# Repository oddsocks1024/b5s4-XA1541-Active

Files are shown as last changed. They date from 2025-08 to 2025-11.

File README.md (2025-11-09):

# b5s4-XA1541-Active
Read &amp; Write C64, C128 and VIC-20 disks directly on a PC using a Commodore drive

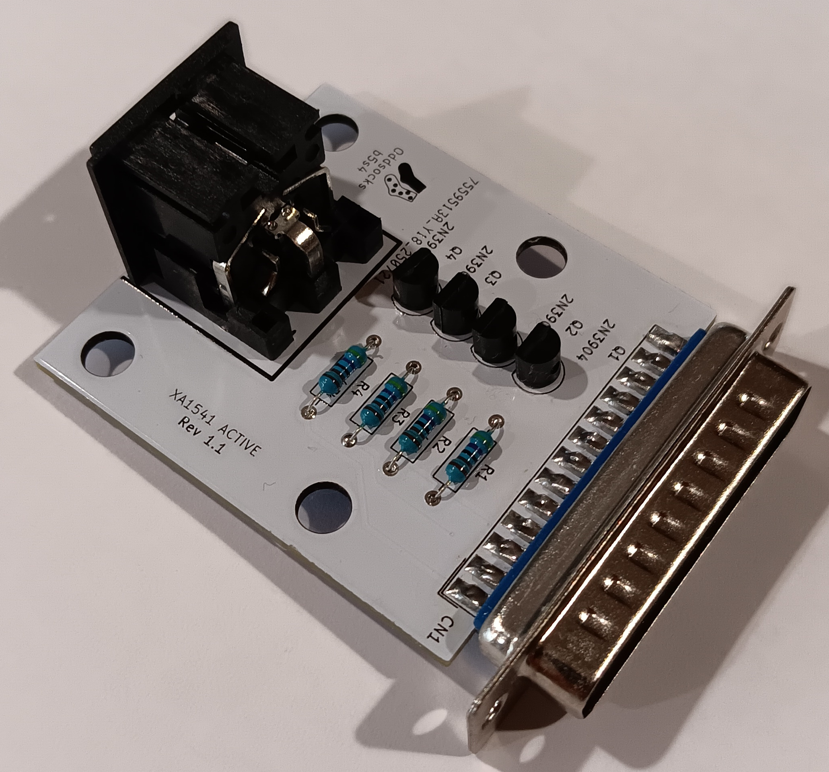
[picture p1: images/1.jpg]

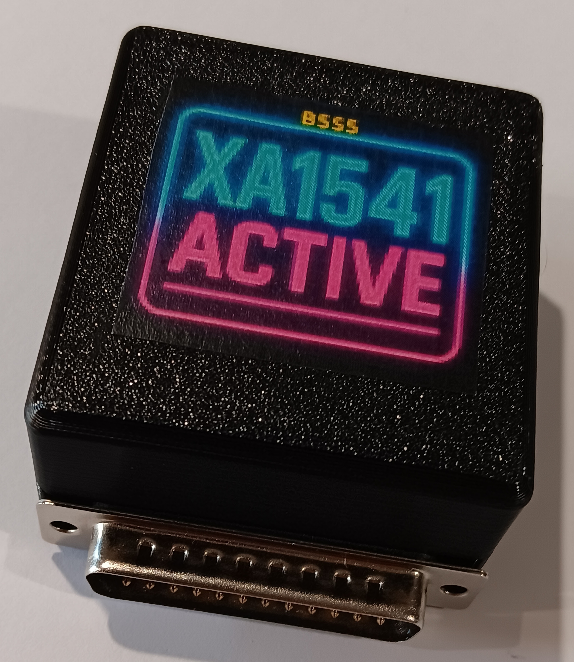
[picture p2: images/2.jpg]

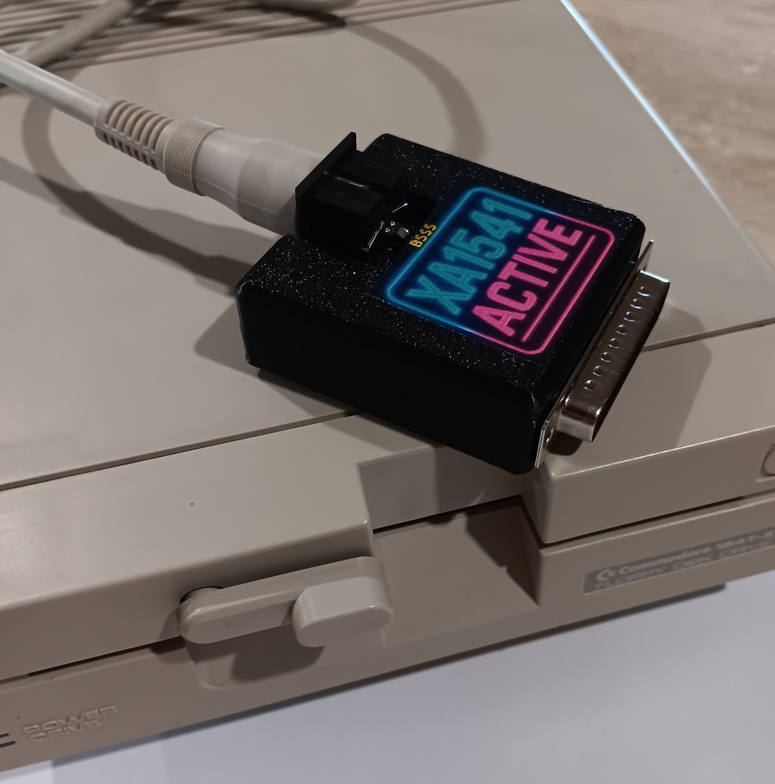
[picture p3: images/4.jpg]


## Description

This is the b5s4 PCB version of the XA1541 Active adapter. It lets you connect Commodore Floppy Disk drives to a PC with a Parallel
Port and read and write to those disks natively. See: https://sta.c64.org/xa1541.html for additional information.

**Compatible Floppy Drives**

* Commodore 1541
* Commodore 1541-II
* Commodore 1570
* Commodore 1571
* Commodore 1581
* ... and compatibles

**Compatible Software**

* The Star Commander
* OpenCBM
* NibTools
* CMBXfer
* Mtap & Ptap
* NIBTools
* cbm4linux

## Bill of Materials

| Qty | Component |
|:---:|---|
| 1 | Female DIN45322 connector |
| 1 | Male DB25 connector - straight - for edge mounting |
| 4 | 2N3904 transistors |
| 4 | 4.7KΩ Axial Resistors - 1/4 watt |

## 3D Printable Case
A 3D printable case specifically designed for this PCB is also available. STLs are included in this repo and there is also a [Thingiverse Page](https://www.thingiverse.com/thing:7099785)

* Designed to use screws as they produce a much nicer, more robust case
* 4 x 3.5mm self-tapping screws to attach the shells. Max length about 12mm

## Support Me
* [My Projects](https://projects.amiga-hardware.com) - Donate on this page
* [Order the PCB](https://www.pcbway.com/project/shareproject/b5s5_XA1541_Active_Read_Write_C64_C128_VIC20_disks_on_PC_ddd3c031.html)
* [Order the Case](https://www.pcbway.com/project/shareproject/b5s4_XA1541_Active_Case_Slimline_af867c8e.html)

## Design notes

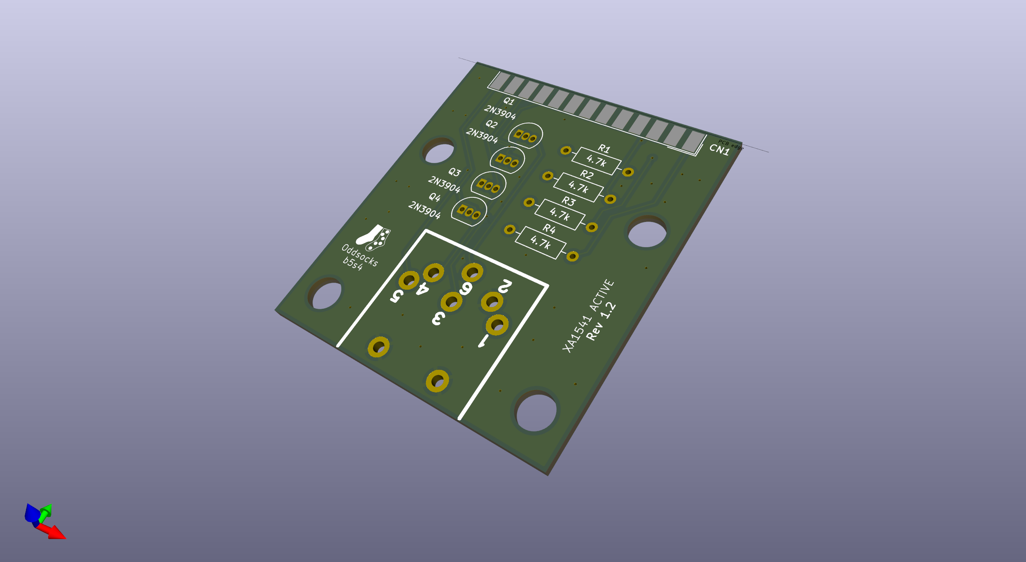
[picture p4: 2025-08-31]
images/b5s4-XA1541-active.png

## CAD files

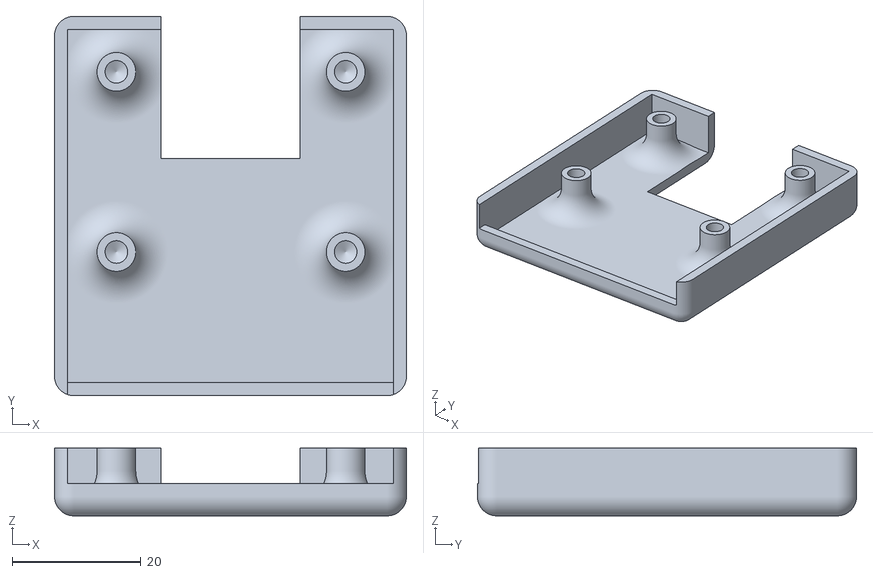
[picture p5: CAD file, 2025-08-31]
STL/XA1541-Active Slim - Top.stl
54.6 x 58.8 x 10.5

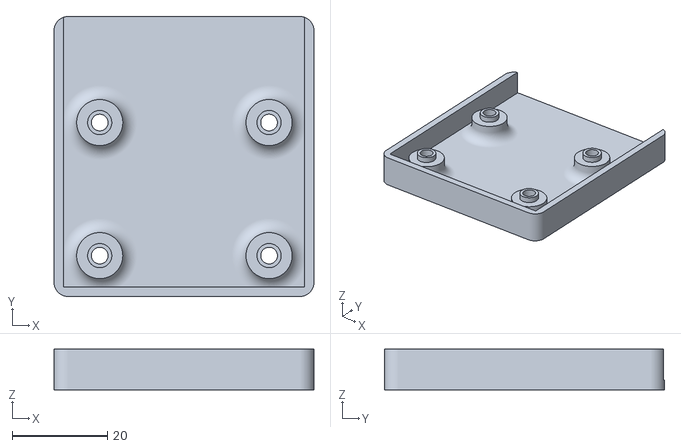
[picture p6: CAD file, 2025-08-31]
STL/XA1541-Active Slim - Bottom.stl
54.6 x 58.8 x 8.51

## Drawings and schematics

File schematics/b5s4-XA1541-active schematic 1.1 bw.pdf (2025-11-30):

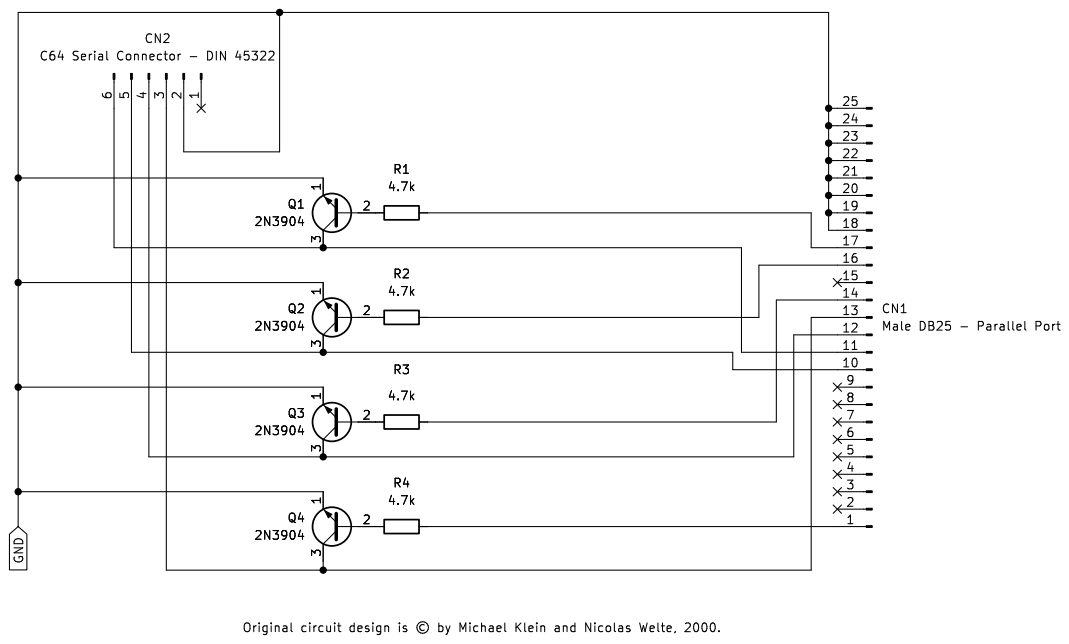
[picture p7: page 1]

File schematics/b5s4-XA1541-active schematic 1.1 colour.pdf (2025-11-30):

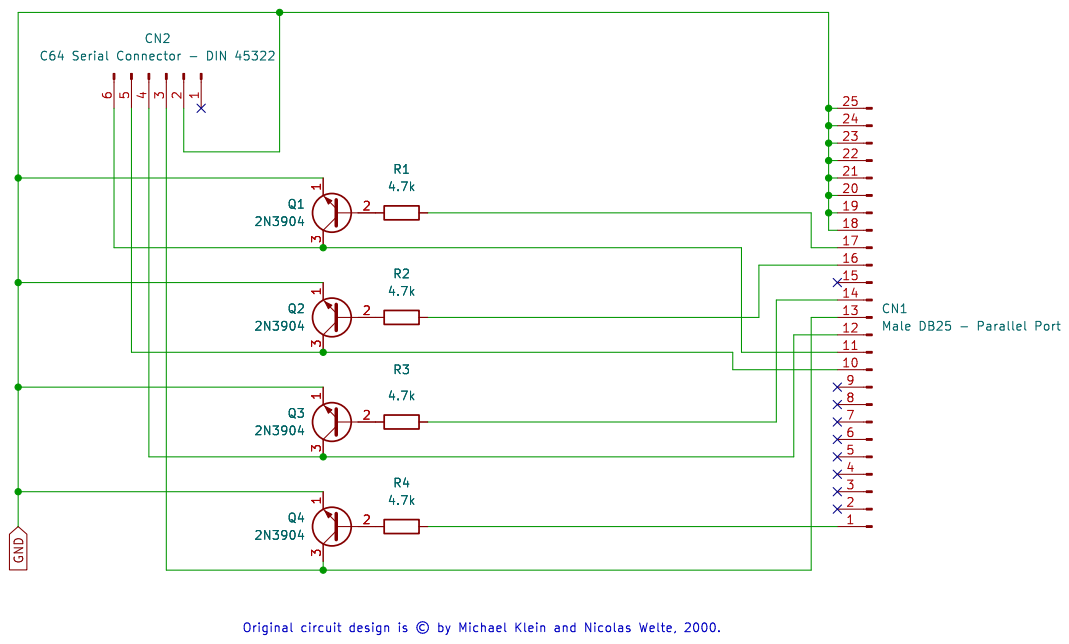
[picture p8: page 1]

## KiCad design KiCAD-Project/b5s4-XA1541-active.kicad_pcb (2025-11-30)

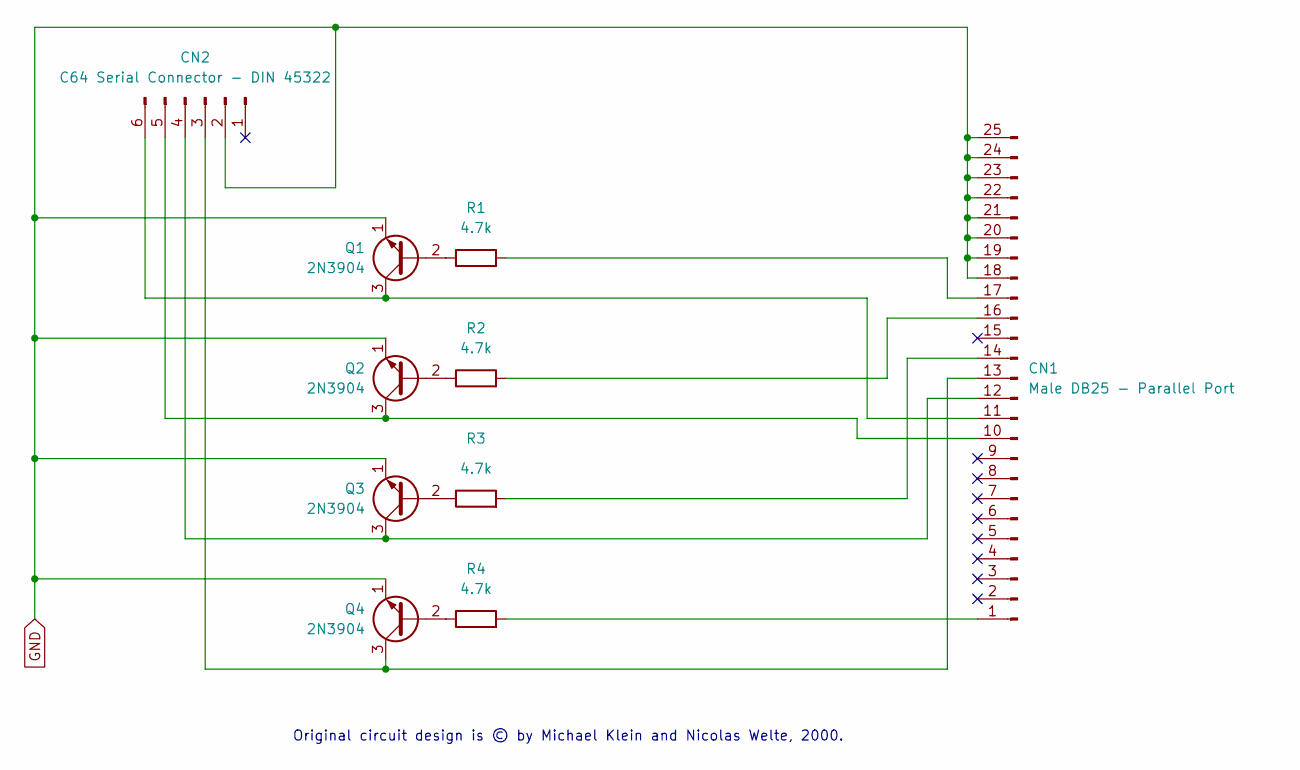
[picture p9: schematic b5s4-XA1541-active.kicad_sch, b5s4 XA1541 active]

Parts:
CN1: Male DB25 - Parallel Port; DSUB-25_Pins_EdgeMount_P2.77mm
CN2: C64 Serial Connector - DIN 45322; C64 Serial Connector
Q1, Q2, Q3, Q4: 2N3904; TO-92_Inline
R1, R2, R3, R4: 4.7k; R_Axial_DIN0207_L6.3mm_D2.5mm_P10.16mm_Horizontal

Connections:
GND: CN1.18, CN1.19, CN1.20, CN1.21, CN1.22, CN1.23, CN1.24, CN1.25, CN2.2, Q1.1 (E), Q2.1 (E), Q3.1 (E), Q4.1 (E)
unnamed: CN1.1, R4.2
unnamed: CN1.10, CN2.5, Q2.3 (C)
unnamed: CN1.11, CN2.6, Q1.3 (C)
unnamed: CN1.12, CN2.4, Q3.3 (C)
unnamed: CN1.13, CN2.3, Q4.3 (C)
unnamed: CN1.14, R3.2
unnamed: CN1.16, R2.2
unnamed: CN1.17, R1.2
unnamed: Q1.2 (B), R1.1
unnamed: Q2.2 (B), R2.1
unnamed: Q3.2 (B), R3.1
unnamed: Q4.2 (B), R4.1

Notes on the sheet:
Original circuit design is © by Michael Klein and Nicolas Welte, 2000.

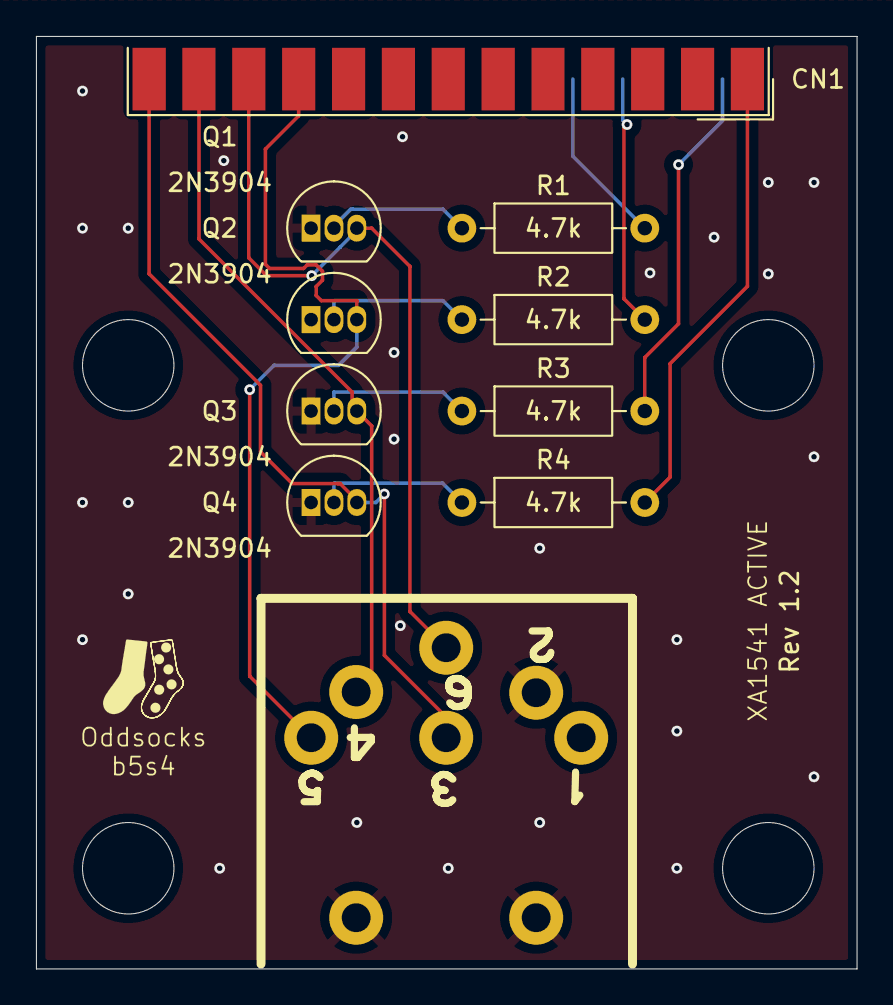
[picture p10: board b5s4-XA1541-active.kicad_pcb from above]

Board: 2 copper layers, 45.6 x 51.8 mm, 10 parts (0 on the bottom side), 13 nets.

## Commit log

2025-11-09 Added gerbers and updated README.md
    [b5s4-XA1541-active-B_Cu.gbl, b5s4-XA1541-active-B_Mask.gbs, b5s4-XA1541-active-B_Paste.gbp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]
2025-11-30 Added PDF schematics
    [b5s4-XA1541-active.kicad_pcb, b5s4-XA1541-active.kicad_sch]

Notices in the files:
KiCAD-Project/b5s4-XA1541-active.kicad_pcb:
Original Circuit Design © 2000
